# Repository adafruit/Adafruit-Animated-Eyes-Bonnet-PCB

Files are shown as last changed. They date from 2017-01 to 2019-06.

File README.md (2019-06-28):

## Adafruit Animated Eyes Bonnet PCB

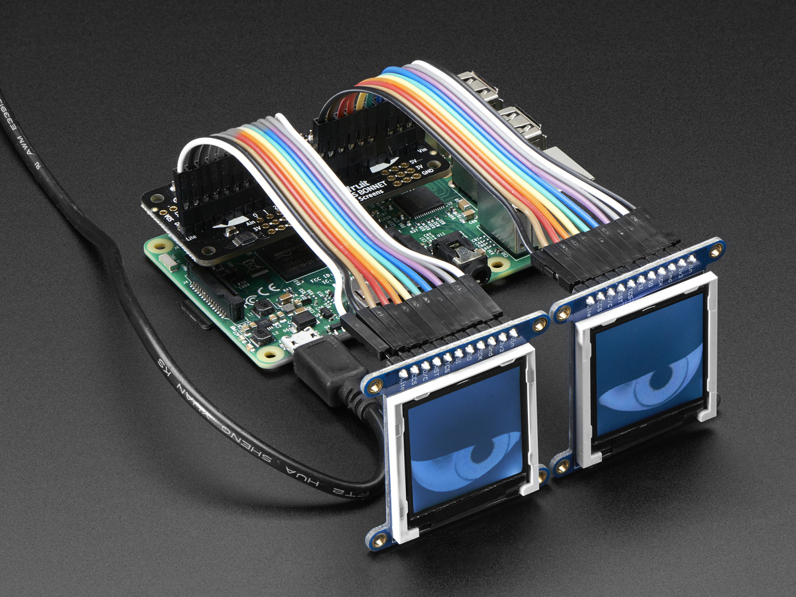
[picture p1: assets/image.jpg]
<a href="http://www.adafruit.com/products/3356"><br/>
Click here to purchase one from the Adafruit shop</a>

PCB files for the Adafruit Animated Eyes Bonnet. Format is EagleCAD schematic and board layout
* http://www.adafruit.com/product/3356

### Description

The Snake Eyes Bonnet is a Raspberry Pi accessory for driving two 128x128 pixel OLED or TFT LCD displays, and also provides four analog inputs for sensors. It's perfect for making cosplay masks, props, spooky sculptures for halloween, animatronics, robots...anything where you want to add a pair of animated eyes!

This product is just the Pi Bonnet itself, and some headers so you can plug it into a Pi. While it will work with any Raspberry Pi with a 2x20 Header (Pi B+, Pi 2, Pi 3, Pi Zero, etc) you'll get best performance from a Pi 3 since we do some heavy duty OpenGL rendering!

**This product doesn't include two displays or connector cables!**

### License

Adafruit invests time and resources providing this open source design, please support Adafruit and open-source hardware by purchasing products from [Adafruit](https://www.adafruit.com)!

Designed by Limor Fried/Ladyada for Adafruit Industries.

Creative Commons Attribution/Share-Alike, all text above must be included in any redistribution. See license.txt for additional details.

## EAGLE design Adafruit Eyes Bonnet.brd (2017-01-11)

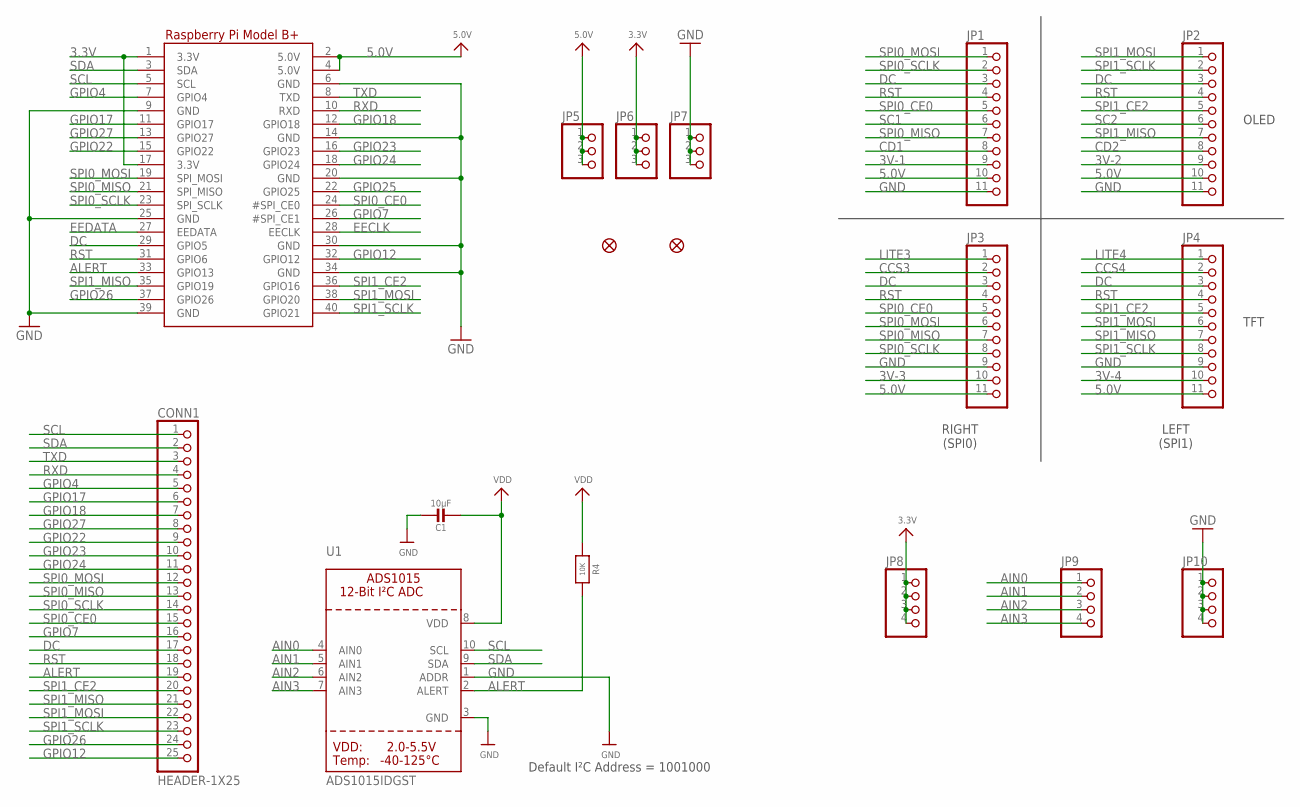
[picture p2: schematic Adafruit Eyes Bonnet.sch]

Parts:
C1: 10µF; 0805-NO
CONN1: HEADER-1X25; 1X25_ROUND_70MIL
FID1, FID2: FIDUCIAL""; FIDUCIAL_1MM
JP1, JP2, JP3, JP4: HEADER-1X11; 1X11_ROUND
JP5, JP6, JP7: HEADER-1X376MIL; 1X03_ROUND_76
JP8, JP9, JP10: HEADER-1X4ROUND; 1X04_ROUND
R4: 10K; 0805-NO
RPI1: RASPBERRYPI_BPLUS_PHAT; PI_BONNET
U1: ADS1015IDGST; MSOP10

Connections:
3.3V: C1.2, JP6.1, JP6.2, JP6.3, JP8.1, JP8.2, JP8.3, JP8.4, R4.1, RPI1.1 (3.3V), RPI1.17 (3.3V), U1.8 (VDD)
3V-1: JP1.9
3V-2: JP2.9
3V-3: JP3.10
3V-4: JP4.10
5.0V: JP1.10, JP2.10, JP3.11, JP4.11, JP5.1, JP5.2, JP5.3, RPI1.2 (5.0V), RPI1.4 (5.0V)
AIN0: JP9.1, U1.4 (AIN0)
AIN1: JP9.2, U1.5 (AIN1)
AIN2: JP9.3, U1.6 (AIN2)
AIN3: JP9.4, U1.7 (AIN3)
ALERT: CONN1.19, R4.2, RPI1.33 (GPIO13), U1.2 (ALERT)
CCS3: JP3.2
CCS4: JP4.2
CD1: JP1.8
CD2: JP2.8
DC: CONN1.17, JP1.3, JP2.3, JP3.3, JP4.3, RPI1.29 (GPIO5)
EECLK: RPI1.28 (EECLK)
EEDATA: RPI1.27 (EEDATA)
GND: C1.1, JP1.11, JP2.11, JP3.9, JP4.9, JP7.1, JP7.2, JP7.3, JP10.1, JP10.2, JP10.3, JP10.4, RPI1.6 (GND), RPI1.9 (GND), RPI1.14 (GND), RPI1.20 (GND), RPI1.25 (GND), RPI1.30 (GND), RPI1.34 (GND), RPI1.39 (GND), U1.1 (ADDR), U1.3 (GND)
GPIO4: CONN1.5, RPI1.7 (GPIO4)
GPIO7: CONN1.16, RPI1.26 (#SPI_CE1)
GPIO12: CONN1.25, RPI1.32 (GPIO12)
GPIO17: CONN1.6, RPI1.11 (GPIO17)
GPIO18: CONN1.7, RPI1.12 (GPIO18)
GPIO22: CONN1.9, RPI1.15 (GPIO22)
GPIO23: CONN1.10, RPI1.16 (GPIO23)
GPIO24: CONN1.11, RPI1.18 (GPIO24)
GPIO25: RPI1.22 (GPIO25)
GPIO26: CONN1.24, RPI1.37 (GPIO26)
GPIO27: CONN1.8, RPI1.13 (GPIO27)
LITE3: JP3.1
LITE4: JP4.1
RST: CONN1.18, JP1.4, JP2.4, JP3.4, JP4.4, RPI1.31 (GPIO6)
RXD: CONN1.4, RPI1.10 (RXD)
SC1: JP1.6
SC2: JP2.6
SCL: CONN1.1, RPI1.5 (SCL), U1.10 (SCL)
SDA: CONN1.2, RPI1.3 (SDA), U1.9 (SDA)
SPI0_CE0: CONN1.15, JP1.5, JP3.5, RPI1.24 (#SPI_CE0)
SPI0_MISO: CONN1.13, JP1.7, JP3.7, RPI1.21 (SPI_MISO)
SPI0_MOSI: CONN1.12, JP1.1, JP3.6, RPI1.19 (SPI_MOSI)
SPI0_SCLK: CONN1.14, JP1.2, JP3.8, RPI1.23 (SPI_SCLK)
SPI1_CE2: CONN1.20, JP2.5, JP4.5, RPI1.36 (GPIO16)
SPI1_MISO: CONN1.21, JP2.7, JP4.7, RPI1.35 (GPIO19)
SPI1_MOSI: CONN1.22, JP2.1, JP4.6, RPI1.38 (GPIO20)
SPI1_SCLK: CONN1.23, JP2.2, JP4.8, RPI1.40 (GPIO21)
TXD: CONN1.3, RPI1.8 (TXD)

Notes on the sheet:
OLED
TFT
RIGHT (SPI0)
LEFT (SPI1)
Default I²C Address = 1001000

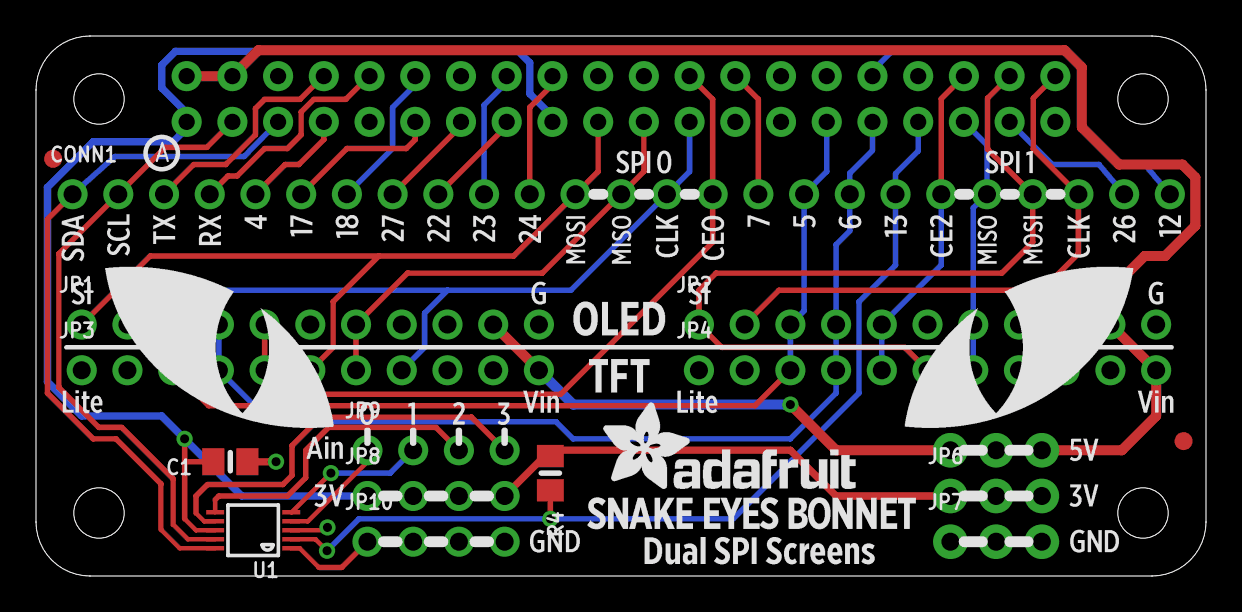
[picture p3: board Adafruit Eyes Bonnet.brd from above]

Board: 2 copper layers, 65.0 x 30.0 mm, 18 parts (0 on the bottom side), 32 nets.

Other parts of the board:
U$8: BONNET_EYES_REVA

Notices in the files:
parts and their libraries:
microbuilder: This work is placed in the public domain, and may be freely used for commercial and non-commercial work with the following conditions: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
